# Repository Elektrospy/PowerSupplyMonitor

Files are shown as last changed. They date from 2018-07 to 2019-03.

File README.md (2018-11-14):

# I2C Powersupply Monitor Hub HitCount (http://hits.dwyl.com/Elektrospy/PowerSupplyMonitor)

This repository contains the schematics and sourcecode for the I2C powersupply monitor hub.

This project is used to monitor and control the HRPG-300 power supplies of the ceiling pixel lamp.
https://github.com/c3e/CeilingPixelLamp

* Control:
	* toggle power output of single power supply
* Monitor:
	* if supply output is active
	* current power consumption for every 5 led panel (10 per power supply)

### Hardware used
* ACS712 30A version
	* Hallsensor based current measuring
* TCA9548A
	* Low-Voltage 8-Channel I2C Switch with Reset
* PCF8575 
	* Remote16-BIT I2C AND SMBus I/O Expander with Interrupt Output
* PCA9685
	* 16-channel, 12-bit PWM Fm+ I2C-bus LED controller
* ADS1015
	* I2C 4-Channel 12-Bit ADC
* PC817
	* High Density Mounting Type Photocoupler

## I2C Hub
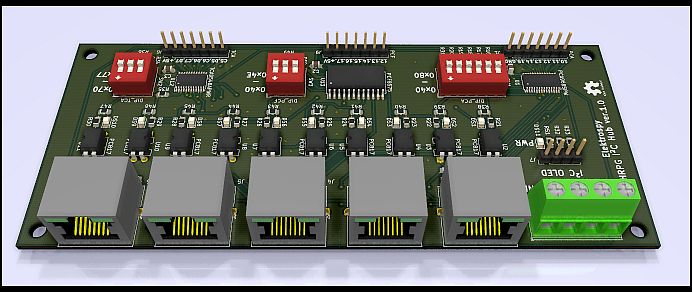
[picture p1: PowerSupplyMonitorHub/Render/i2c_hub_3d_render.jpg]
I2C Hub Render


I2C Hub Board for I2C Nodes

## I2C Node
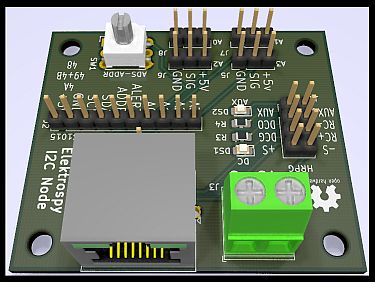
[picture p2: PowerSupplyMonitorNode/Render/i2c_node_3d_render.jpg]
I2C Node Render

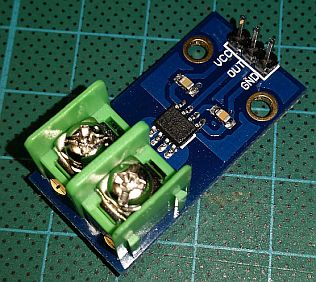
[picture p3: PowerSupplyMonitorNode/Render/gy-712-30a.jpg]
I2C Node Render


I2C Node Board + GY-712 30A

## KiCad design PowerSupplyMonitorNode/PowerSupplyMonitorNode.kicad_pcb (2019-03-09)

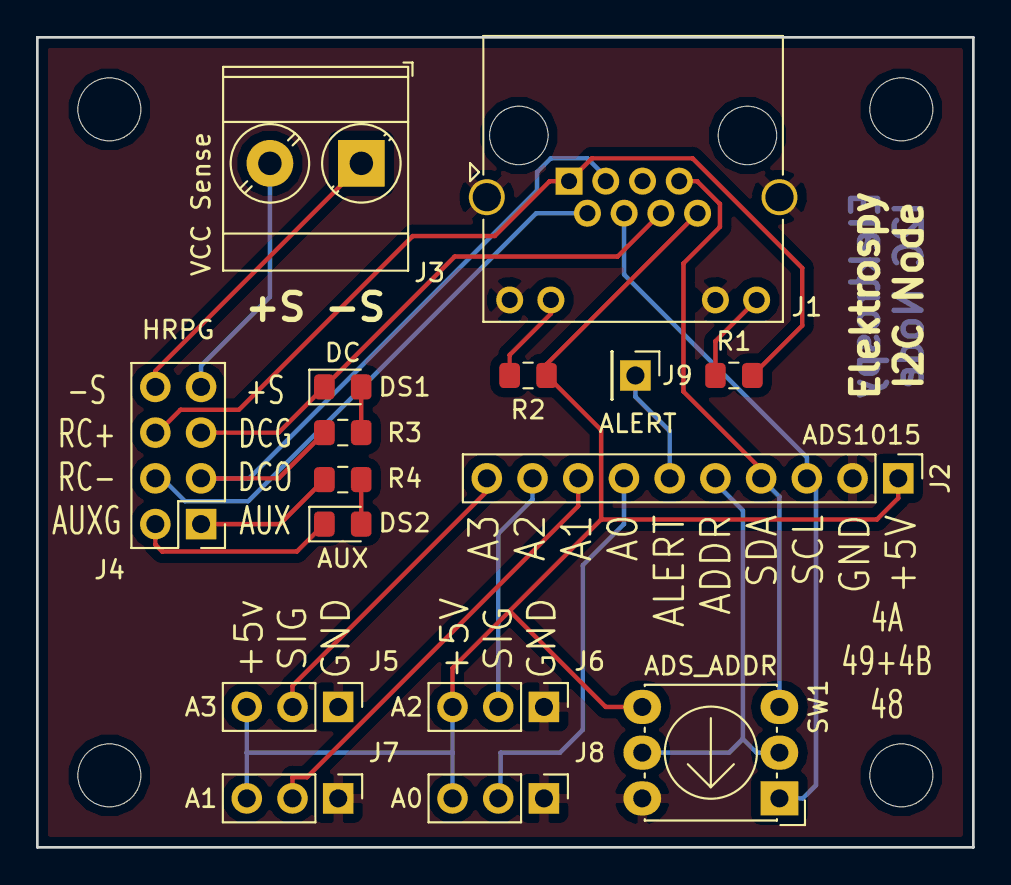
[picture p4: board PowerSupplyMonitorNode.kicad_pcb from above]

Board: 2 copper layers, 52.0 x 45.0 mm, 20 parts (0 on the bottom side), 22 nets.

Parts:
DS1: DC; LED_0805_2012Metric_Pad1.15x1.40mm_HandSolder
DS2: AUX; LED_0805_2012Metric_Pad1.15x1.40mm_HandSolder
J1: RJ45 PWR; RJ45_Amphenol_RJHSE538X
J2: ADS1015; PinHeader_1x10_P2.54mm_Vertical
J3: VCC Sense; TerminalBlock_Phoenix_MKDS-3-2-5.08_1x02_P5.08mm_Horizontal
J4: HRPG; PinHeader_2x04_P2.54mm_Vertical
J5: A3; PinHeader_1x03_P2.54mm_Vertical
J6: A2; PinHeader_1x03_P2.54mm_Vertical
J7: A1; PinHeader_1x03_P2.54mm_Vertical
J8: A0; PinHeader_1x03_P2.54mm_Vertical
J9: ALERT; PinHeader_1x01_P2.54mm_Vertical
MH1, MH2, MH3, MH4: MountingHole; MountingHole_3.5mm
R1, R2, R3, R4: 220; R_0805_2012Metric_Pad1.15x1.40mm_HandSolder
SW1: ADS_ADDR; CTS_ 220AD_0

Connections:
+5V: J1.8, J2.1, J5.3, J6.3, J7.3, J8.3, R2.1, SW1.3
/+S: J3.2, J4.7
/-S: J3.1, J4.8
/A0: J2.7, J8.2
/A1: J2.8, J7.2
/A2: J2.9, J6.2
/A3: J2.10, J5.2
/ADDR: J2.5, SW1.1
/ALERT: J2.6, J9.1
/AUX: J4.1, R4.1
/AUXG: DS2.1, J4.2
/DC_GND: DS1.1, J1.6, J4.5
/DC_OK: J1.3, J4.3, R3.2
/RC+: J1.1, J4.6, R1.1
/RC-: J1.2, J4.4
/SCL: J1.4, J2.3, SW1.5
/SDA: J1.7, J2.4, SW1.4
GND: J1.5, J1.9, J1.11, J1.SH, J2.2, J5.1, J6.1, J7.1, J8.1, SW1.2
unnamed: DS1.2, R3.1
unnamed: DS2.2, R4.2
unnamed: J1.10, R2.2
unnamed: J1.12, R1.2

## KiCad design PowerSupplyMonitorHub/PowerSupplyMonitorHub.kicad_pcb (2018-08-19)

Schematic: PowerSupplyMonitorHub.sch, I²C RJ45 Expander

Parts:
C1, C2, C3: 0.1uF; C_0805_2012Metric_Pad1.15x1.40mm_HandSolder
DS1: RC0; LED_0805_2012Metric_Pad1.15x1.40mm_HandSolder
DS2: DC0; LED_0805_2012Metric_Pad1.15x1.40mm_HandSolder
DS3: RC1; LED_0805_2012Metric_Pad1.15x1.40mm_HandSolder
DS4: DC1; LED_0805_2012Metric_Pad1.15x1.40mm_HandSolder
DS5: RC2; LED_0805_2012Metric_Pad1.15x1.40mm_HandSolder
DS6: DC2; LED_0805_2012Metric_Pad1.15x1.40mm_HandSolder
DS7: RC3; LED_0805_2012Metric_Pad1.15x1.40mm_HandSolder
DS8: DC3; LED_0805_2012Metric_Pad1.15x1.40mm_HandSolder
DS9: RC4; LED_0805_2012Metric_Pad1.15x1.40mm_HandSolder
DS10: DC4; LED_0805_2012Metric_Pad1.15x1.40mm_HandSolder
DS11: PWR; LED_0805_2012Metric_Pad1.15x1.40mm_HandSolder
J1: CON_PCA; PinHeader_1x07_P2.54mm_Vertical
J2: RJ45 PWR 0; RJ45_Amphenol_RJHSE538X
J3: RJ45 PWR 1; RJ45_Amphenol_RJHSE538X
J4: RJ45 PWR 2; RJ45_Amphenol_RJHSE538X
J5: RJ45 PWR 3; RJ45_Amphenol_RJHSE538X
J6: RJ45 PWR 4; RJ45_Amphenol_RJHSE538X
J7: OLED I2C; PinHeader_1x04_P2.54mm_Vertical
J8: CON_TCA; PinHeader_1x07_P2.54mm_Vertical
J9: CON_PCF; PinHeader_1x07_P2.54mm_Vertical
J10: Input; TerminalBlock_Phoenix_MKDS-3-4-5.08_1x04_P5.08mm_Horizontal
MH1, MH2, MH3, MH4: MountingHole; MountingHole_3.5mm
R1, R2, R3, R4, R5, R6, R7, R8, R9, R10, R11, R12, R13, R14, R15, R21, R23, R25, R27, R29, R38, R39, R40, R41, R42, R43, R44, R45, R46, R47, R51: 220; R_0805_2012Metric_Pad1.15x1.40mm_HandSolder
R16, R17, R18, R19, R20, R31, R32, R33, R34, R35, R36, R37, R48, R49, R50: 10K; R_0805_2012Metric_Pad1.15x1.40mm_HandSolder
SW1: DIP_PCA; SW_DIP_SPSTx06_Slide_9.78x17.42mm_W7.62mm_P2.54mm
SW2: DIP_TCA; SW_DIP_SPSTx03_Slide_9.78x9.8mm_W7.62mm_P2.54mm
SW3: DIP_PCF; SW_DIP_SPSTx03_Slide_9.78x9.8mm_W7.62mm_P2.54mm
U1: PCA9685PW; TSSOP-28_4.4x9.7mm_P0.65mm
U2, U3, U4, U5, U6, U7, U8, U9, U10, U11: PC817; DIP-4_W7.62mm
U12: TCA9548APWR; TSSOP-24_4.4x7.8mm_P0.65mm
U13: PCF8575; SOIC-24W_7.5x15.4mm_P1.27mm; MPN PCF8575TS/1,112

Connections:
+5V: C1.1, C2.2, C3.2, J2.8, J3.8, J4.8, J5.8, J6.8, J7.2, J8.1, J9.1, J10.2, R21.2, R23.2, R25.2, R27.2, R29.2, R32.1, R33.1, R35.2, R38.1, R39.1, R40.1, R41.1, R42.1, R43.1, R44.1, R45.1, R46.1, R47.1, R51.1, SW1.1, SW1.2, SW1.3, SW1.4, SW1.5, SW1.6, SW2.1, SW2.2, SW2.3, SW3.1, SW3.2, SW3.3, U1.28, U12.24, U13.24
/DATA_0: R1.1, U1.6
/DATA_1: R3.1, U1.8
/DATA_2: R5.1, U1.10
/DATA_3: R7.1, U1.12
/DATA_4: R9.1, U1.15
/DC-GND_0: J2.6, U3.2
/DC-GND_1: J3.6, U5.2
/DC-GND_2: J4.6, U7.2
/DC-GND_3: J5.6, U9.2
/DC-GND_4: J6.6, U11.2
/DC-OK_0: J2.3, R11.1
/DC-OK_1: J3.3, R12.1
/DC-OK_2: J4.3, R13.1
/DC-OK_3: J5.3, R14.1
/DC-OK_4: J6.3, R15.1
/DC_0: DS2.1, U3.4, U13.5
/DC_1: DS4.1, U5.4, U13.7
/DC_2: DS6.1, U7.4, U13.9
/DC_3: DS8.1, U9.4, U13.11
/DC_4: DS10.1, U11.4, U13.14
/LINK_0: R2.1, U1.7
/LINK_1: R4.1, U1.9
/LINK_2: R6.1, U1.11
/LINK_3: R8.1, U1.13
/LINK_4: R10.1, U1.16
/RC+_0: J2.1, U2.4
/RC+_1: J3.1, U4.4
/RC+_2: J4.1, U6.4
/RC+_3: J5.1, U8.4
/RC+_4: J6.1, U10.4
/RC-_0: J2.2, U2.3
/RC-_1: J3.2, U4.3
/RC-_2: J4.2, U6.3
/RC-_3: J5.2, U8.3
/RC-_4: J6.2, U10.3
/RC_0: DS1.1, U2.2, U13.4
/RC_1: DS3.1, U4.2, U13.6
/RC_2: DS5.1, U6.2, U13.8
/RC_3: DS7.1, U8.2, U13.10
/RC_4: DS9.1, U10.2, U13.13
/SCL: J7.3, J10.3, R32.2, U1.26, U12.22, U13.22
/SCL0: J2.4, U12.5
/SCL1: J3.4, U12.7
/SCL2: J4.4, U12.9
/SCL3: J5.4, U12.11
/SCL4: J6.4, U12.14
/SDA: J7.4, J10.4, R33.2, U1.27, U12.23, U13.23
/SDA0: J2.7, U12.4
/SDA1: J3.7, U12.6
/SDA2: J4.7, U12.8
/SDA3: J5.7, U12.10
/SDA4: J6.7, U12.13
GND: C1.2, C2.1, C3.1, DS11.1, J1.1, J2.5, J2.9, J2.11, J2.SH, J3.5, J3.9, J3.11, J3.SH, J4.5, J4.9, J4.11, J4.SH, J5.5, J5.9, J5.11, J5.SH, J6.5, J6.9, J6.11, J6.SH, J7.1, J10.1, R16.2, R17.2, R18.2, R19.2, R20.2, R31.2, R34.1, R36.1, R37.1, R48.2, R49.2, R50.2, U1.14, U1.23, U1.25, U3.3, U5.3, U7.3, U9.3, U11.3, U12.12, U13.12
unnamed: DS1.2, R38.2
unnamed: DS2.2, R39.2
unnamed: DS3.2, R40.2
unnamed: DS4.2, R41.2
unnamed: DS5.2, R42.2
unnamed: DS6.2, R43.2
unnamed: DS7.2, R44.2
unnamed: DS8.2, R45.2
unnamed: DS9.2, R46.2
unnamed: DS10.2, R47.2
unnamed: DS11.2, R51.2
unnamed: J1.2, U1.22
unnamed: J1.3, U1.21
unnamed: J1.4, U1.20
unnamed: J1.5, U1.19
unnamed: J1.6, U1.18
unnamed: J1.7, U1.17
unnamed: J2.10, R2.2
unnamed: J2.12, R1.2
unnamed: J3.10, R4.2
unnamed: J3.12, R3.2
unnamed: J4.10, R6.2
unnamed: J4.12, R5.2
unnamed: J5.10, R8.2
unnamed: J5.12, R7.2
unnamed: J6.10, R10.2
unnamed: J6.12, R9.2
unnamed: J8.2, U12.19
unnamed: J8.3, U12.20
unnamed: J8.4, U12.17
unnamed: J8.5, U12.18
unnamed: J8.6, U12.15
unnamed: J8.7, U12.16
unnamed: J9.2, U13.20
unnamed: J9.3, U13.19
unnamed: J9.4, U13.18
unnamed: J9.5, U13.17
unnamed: J9.6, U13.16
unnamed: J9.7, U13.15
unnamed: R11.2, U3.1
unnamed: R12.2, U5.1
unnamed: R13.2, U7.1
unnamed: R14.2, U9.1
unnamed: R15.2, U11.1
unnamed: R16.1, SW1.7, U1.24
unnamed: R17.1, SW1.8, U1.5
unnamed: R18.1, SW1.9, U1.4
unnamed: R19.1, SW1.10, U1.3
unnamed: R20.1, SW1.11, U1.2
unnamed: R21.1, U2.1
unnamed: R23.1, U4.1
unnamed: R25.1, U6.1
unnamed: R27.1, U8.1
unnamed: R29.1, U10.1
unnamed: R31.1, SW1.12, U1.1
unnamed: R34.2, SW2.4, U12.1
unnamed: R35.1, U12.3
unnamed: R36.2, SW2.5, U12.2
unnamed: R37.2, SW2.6, U12.21
unnamed: R48.1, SW3.6, U13.21
unnamed: R49.1, SW3.5, U13.2
unnamed: R50.1, SW3.4, U13.3

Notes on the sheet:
Remote State LEDs

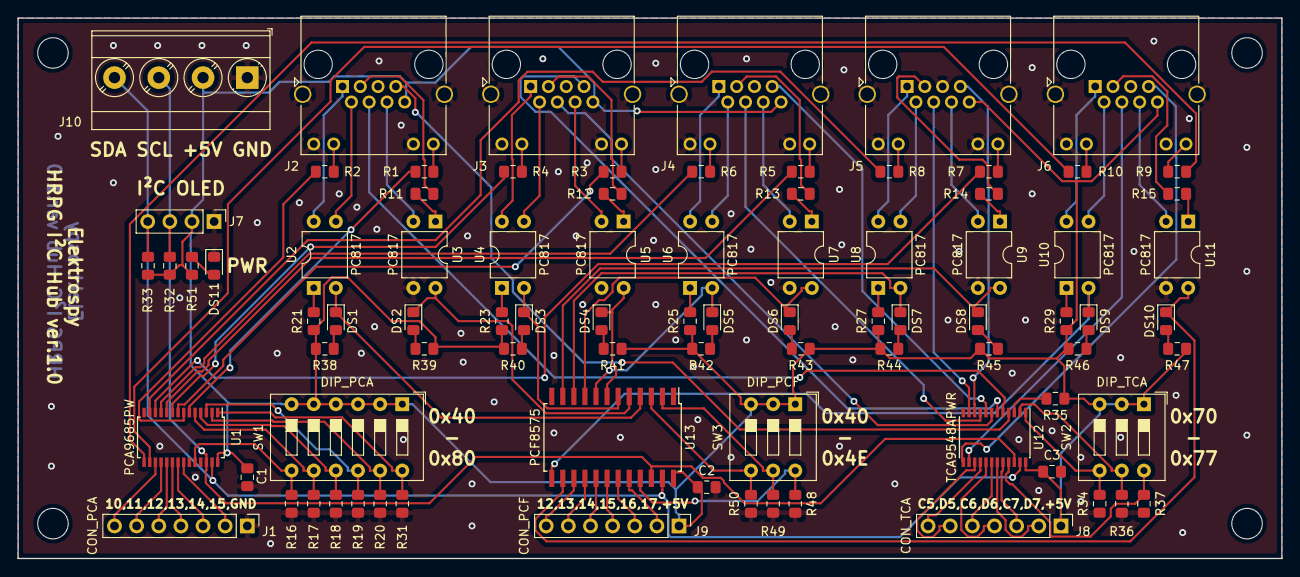
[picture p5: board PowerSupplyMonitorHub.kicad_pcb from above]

Board: 2 copper layers, 145.0 x 62.0 mm, 90 parts (0 on the bottom side), 116 nets.

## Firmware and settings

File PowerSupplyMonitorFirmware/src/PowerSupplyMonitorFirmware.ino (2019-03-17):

#include <Wire.h> // i2c stuff
#include "i2cHub.h"
#include "i2cHubDebug.h"
#include "i2cHubDisplay.h"
#define DEBUG false

// Arduino 328p, SDA: A4, SCL: A5
// ESP8266, SDA: D1, SCL: D2
#define PIN_SDA D1
#define PIN_SCL D2
const unsigned long serialBautrate = 115200;
const uint32_t i2cClockSpeed = 400000;
i2cHub nodeHub = i2cHub();
i2cHubDisplay nodeHubDisplay = i2cHubDisplay(&nodeHub);
#if DEBUG
i2cHubDebug nodeHubDebug = i2cHubDebug(&nodeHub);
#endif

void setup() {
    Serial.begin(serialBautrate);
    // init i2c wire bus
    Wire.begin(PIN_SDA, PIN_SCL);
    // Supported baud rates are 100kHz, 400kHz, and 1000kHz
    Wire.setClock(i2cClockSpeed);
    // init nodeHub for i2c usage
    nodeHub.init();
    // i2c oled settings
    nodeHubDisplay.init();
}

void loop() {
    nodeHub.run();
    nodeHubDisplay.run();
    #if DEBUG
    nodeHubDebug.debugNodePrint();
    nodeHubDebug.debugNodePowerSupplys();
    #endif
}    

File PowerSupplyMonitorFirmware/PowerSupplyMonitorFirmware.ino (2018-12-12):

#include <Wire.h> // i2c stuff
#include <TwoWireMux.h>
#include <TI_TCA9548A.h>
#include "i2cNode.h"

#define DEBUG true

// Arduino 328p, SDA: A4, SCL: A5
// ESP8266, SDA: D1, SCL: D2
#define PIN_SDA D1
#define PIN_SCL D2

const uint8_t numberOfNodes=5;

TI_TCA9548A nodeMuxer(&Wire);
Adafruit_ADS1015 ads;
i2cNode i2cNodeList[numberOfNodes];

void initNodes() {
	for(uint8_t currentNode=0; currentNode < numberOfNodes; currentNode++) {
		i2cNodeList[currentNode] = i2cNode(&nodeMuxer, currentNode);
	}
}

void setup() {
#if DEBUG
    Serial.begin(115200);
#endif

    Wire.begin(PIN_SDA, PIN_SCL); // Wire must be started first
    Wire.setClock(400000); // Supported baud rates are 100kHz, 400kHz, and 1000kHz

    nodeMuxer.setBaseChannelMask(31); // 0001 1111 Enable Channel 0-4
    nodeMuxer.selectChannel(0);
    ads.begin();
}

void loop() {
	Serial.print("Node #");
	Serial.print(0);
	Serial.print(" A:");
	Serial.println(ads.readADC_SingleEnded(0));
	delay(1000);

	/*
#if DEBUG
    for(uint8_t currentNode=0; currentNode < numberOfNodes; currentNode++) {
		Serial.print("Node #");
		Serial.print(currentNode);
		Serial.print(" A:");
		Serial.println(i2cNodeList[currentNode].getAmpereForOutput(0));
    }
    Serial.println("===============");
    delay(500);
#endif
*/
}

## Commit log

2018-07-26 initial commit added kicad project added schematic of main i2c hub added datasheets for ics
    [PowerSupplyMonitorHub.kicad_pcb, PowerSupplyMonitorHub.sch]
2018-07-27 added dip switches to i2c ics for adress selection added pullup resistors to i2c input lines added placeholder footprint for pcf8575 added minimal pcb placement for testing
    [PowerSupplyMonitorHub.kicad_pcb, PowerSupplyMonitorHub.sch]
2018-07-27 changed package and footprint from sop to soi for pcf8575
    [PowerSupplyMonitorHub.kicad_pcb, PowerSupplyMonitorHub.sch]
2018-07-27 updated 3d pcb render to show new dcf8575 package
2018-07-27 added new 3d render of front and back view of pcb added pcb routing from autorouter added power led indicator added i2c ic adress ranges to silkscreen added unused ic pins pinout info silkscreen adde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
    [PowerSupplyMonitorHub.kicad_pcb, PowerSupplyMonitorHub.sch]
2018-07-28 added new pcb i2c node
    added new datasheet for dts 220ADC04 coded rotary
    added new datasheet for hrpg 300 power supply
    added gerber files for i2c hub and node
    added new 3d render for i2c node
    [PowerSupplyMonitorHub.kicad_pcb, PowerSupplyMonitorNode.kicad_pcb, PowerSupplyMonitorNode.sch]
2018-07-28 added more pinout infos for i2c node to silkscreen
    updated render of i2c node so show new silkscreen stuff
    [PowerSupplyMonitorNode.kicad_pcb]
2018-07-28 added minimal readme
    added many vias for ground front and back plane
    updated 3d render of i2c hub pcb
    updated gerber archive files
    [PowerSupplyMonitorHub.kicad_pcb, PowerSupplyMonitorHub.sch, PowerSupplyMonitorNode.kicad_pcb]
2018-07-30 updated readme and license file
    added datasheet for ads1015
    added datasheet for pca9685
    added foto of gy-712 30a sensor
    added small changes to pcbs
    updated 3d render of pcbs
    [PowerSupplyMonitorHub.kicad_pcb, PowerSupplyMonitorHub.sch, PowerSupplyMonitorNode.kicad_pcb]
2018-08-19 added basic pcb testing firmware
    it scans for i2c devices and blinks some leds
2018-08-19 fixed pcb errors
    swapped gnd and vcc pin of 4 position switch to fix first two addresses
    added custom 3d model for 4 position switch as step file
    added custom library for 4 position switch
    fixed routing of feedback signal lines (dc0-dc5)
    removed double current limiting led resistors
    [PowerSupplyMonitorHub.kicad_pcb, PowerSupplyMonitorHub.sch, PowerSupplyMonitorNode.kicad_pcb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]
2018-08-19 added more vias for gnd plane on both sides
    [PowerSupplyMonitorHub.kicad_pcb]
2018-11-04 added small changes to power supply pcbs added needed libraries to node firmware folder added node test program for wemos D1 mini as master added placeholder header and source file for new firmware
    [PowerSupplyMonitorHub.kicad_pcb, PowerSupplyMonitorHub.sch, PowerSupplyMonitorNode.kicad_pcb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]
2018-11-20 added basic contruct for firmware image added private method to calculate average adc milliampere value added public method to get the average milliampere value for a output changed from single value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
2019-03-05 added new blank class for i2chub added new debug print for milliampere cleanup of i2cnode code
2019-03-06 added basic methods to i2chub class
2019-03-07 removed testing platformio environment removed testing ino file added missing tca port switching fixed same input value for all nodes and channels
    [PowerSupplyMonitorFirmware.ino]
2019-03-08 removed unit tests because of forced cloud account changed limit of float debug print
2019-03-09 fixed kicad project files with older copy
    [PowerSupplyMonitorHub.kicad_pcb, PowerSupplyMonitorHub.sch, PowerSupplyMonitorNode.kicad_pcb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]
2019-03-10 added new lib dependency PCF857X added basic port initialization for pcf6575 the start state for the powersupplies is set to off
2019-03-11 added basic powersupply toggle over buttons
2019-03-13 added basic testing loop to toggle power supplies
2019-03-14 added basic test for i2c oled display
2019-03-15 added test dashboard for adc in milliampere
2019-03-15 fixed ampere prescaler from 10 to 12bit removed milliampere values removed milliampere debug messages
2019-03-16 flipped adc ampere inputs of nodes to match up with final cabeling
2019-03-17 added new dashboard with sum ampere added new fake dashboard for ip info added progress bar for sum ampere added dashboard circles menu display added dashboard switches to last button
2019-03-17 added new gain value for adc changed progress bar from rounded to normal box draw added switching for positiv and negativ ampere values
2019-03-17 added small note for middle adc value
